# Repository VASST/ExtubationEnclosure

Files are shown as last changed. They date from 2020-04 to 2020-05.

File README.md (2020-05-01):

# Aerosol Containment Enclosure

This page details the design, materials, and construction of an aerosol containment enclosure for hospital settings. It has been developed in a partnership between physicians at University Hospital, London Health Sciences Centre (LHSC) and engineers at Robarts Research Institute (RRI), Western University.

## Publication
This work can be read in detail here:
* [A multipurpose portable negative air flow isolation chamber for aerosol generating medical procedures during the COVID-19 pandemic
Cubillos, J. et al.](https://bjanaesthesia.org/article/S0007-0912(20)30274-9/fulltext)

## Contacts
- Adam Rankin (arankin -at- robarts.ca), RRI, hardware
- John Moore (jmoore -at- robarts.ca), RRI, hardware
- Daniel Bainbridge, LHSC, anesthesiologist
- Kevin Armstrong, LHSC, anesthesiologist
- Javier Cubillos, LHSC, anesthesiologist

## References
- A 3 sided + top design with rigid plastic walls. Excellent spatter containment but no management of dispersal into the surrounding airspace; limited range of motion for physicians; excellent access for tubing/tools/hands:
  - [Barrier Enclosure during Endotracheal Intubation](https://www.nejm.org/doi/full/10.1056/NEJMc2007589)

# Designs
* [Fully 3D Printed Cage](./Designs/Ribcage.md)
* [PVC Pipe Cage](./Designs/HWCage.md)

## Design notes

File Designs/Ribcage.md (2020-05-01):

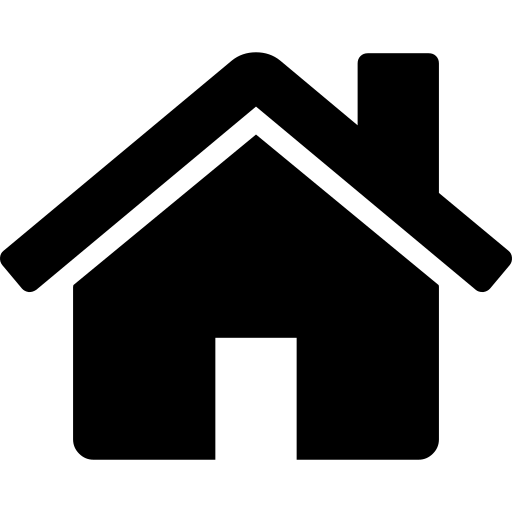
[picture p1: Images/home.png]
[ - Main Page](../README.md)

# Fully 3D Printed Cage
This design is intended to be built using 3D printed, modular parts. Two example designs are presented here, but the idea is that any combination can be used as needed.

## Materials
- 3D printed parts:
  - ABS or PETG recommended as a printing material for cleaning purposes
  - PLA is not recommended due to its lower glass transition and melting points
- Hardware:
  - Use any of: M5x15, 10-24x5/8" or 10-32x5/8" with corresponding nylon lock-nut

## CAD
- [VentilatorFrame-01.4.stp](../Models/VentilatorFrame-01.4.stp)

## Printing
- Parts are designed to be printed on hobby grade 3D printers, use settings as recommended by your printer and filament guidelines

### Parts
- [VentilatorFrame_BaseLong](../Models/VentilatorFrame_BaseLong.stl)
- [VentilatorFrame_BaseShort](../Models/VentilatorFrame_BaseShort.stl)
- [VentilatorFrame_VerticalPost](../Models/VentilatorFrame_VerticalPost.stl)
- [VentilatorFrame_VerticalExtension](../Models/VentilatorFrame_VerticalExtension.stl)
- [VentilatorFrame_HalfArch](../Models/VentilatorFrame_HalfArch.stl)
- [VentilatorFrame_WholeArch](../Models/VentilatorFrame_WholeArch.stl)
- [VentilatorFrame_ArchSpacer](../Models/VentilatorFrame_ArchSpacer.stl)
- [VentilatorFrame_IOPort](../Models/VentilatorFrame_IOPort.stl)

## Sample Arrangements
Presented here are some sample arrangements that may be useful for your needs:

### Example 1
This design features an IO port and easy access to the face at the expense of patient comfort

#### Preview

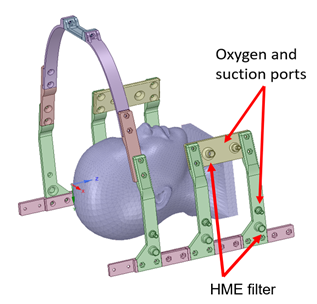
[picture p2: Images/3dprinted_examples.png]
First design preview


#### Quantities
- 6@ VentilatorFrame_VerticalPost
- 2@ VentilatorFrame_VerticalExtension (optional, repeat as many as necessary)
- 2@ VentilatorFrame_IOPort
- 2@ VentilatorFrame_HalfArch
- 1@ VentilatorFrame_ArchSpacer (optional, repeat as many as necessary)
- 2@ VentilatorFrame_BaseShort
- 2@ VentilatorFrame_BaseLong

### Example 2
This configuration provides more room over the patients face, but has limited access from the sides.

#### Preview

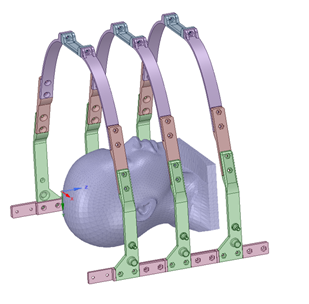
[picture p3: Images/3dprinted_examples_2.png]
Second design preview


#### Quantities
- 6@ VentilatorFrame_VerticalPost
- 6@ VentilatorFrame_VerticalExtension (optional, repeat as many as necessary)
- 6@ VentilatorFrame_HalfArch
- 3@ VentilatorFrame_ArchSpacer (optional, repeat as many as necessary)
- 2@ VentilatorFrame_BaseShort
- 2@ VentilatorFrame_BaseLong

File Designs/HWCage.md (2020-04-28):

[ - Main Page](../README.md)

# PVC Pipe Cage
This design is intended to be built using common plumbing parts that would most likely be available at your local hardware store. A number of 3D printed pieces are included as optional enhancements, but are not necessary for the basic structure.

## Video
A video of the cage in action can be seen at [https://youtu.be/DAdx9pdc0is](https://youtu.be/DAdx9pdc0is)

## North American
Design based on 3/4" ID PVC plumbing pipe

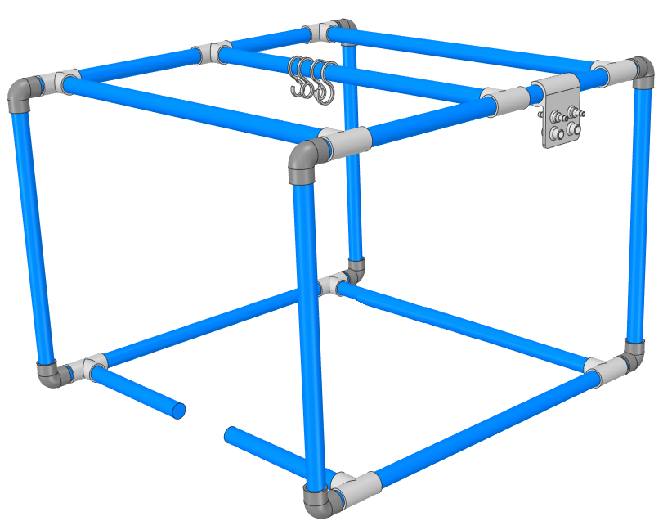
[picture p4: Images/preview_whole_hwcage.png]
Whole design preview


### Materials
- 3/4" pipe sections (example: [https://www.mcmaster.com/48925k12](https://www.mcmaster.com/48925k12]))
  - corner assemblies
    - 8@ 2"
  - side joins
    - 4@ 23.5"
  - side verticals
    - 4@ 18.5"s
  - side horizontals
    - 2@ 21"
    - 4@ 10.5"
  - Optional: 2@ length determined by bed/patient/mounting system (see assembly instructions for detail)
- 3/4" pipe fittings
  - 8@ 90deg female-female (example: [https://www.mcmaster.com/4880k22](https://www.mcmaster.com/4880k22))
  - 10@ Tee: female-female-female (example: [https://www.mcmaster.com/4880k42](https://www.mcmaster.com/4880k42))

### Assembly

First left side, then right side, then join them together.

#### Right Side: Preview

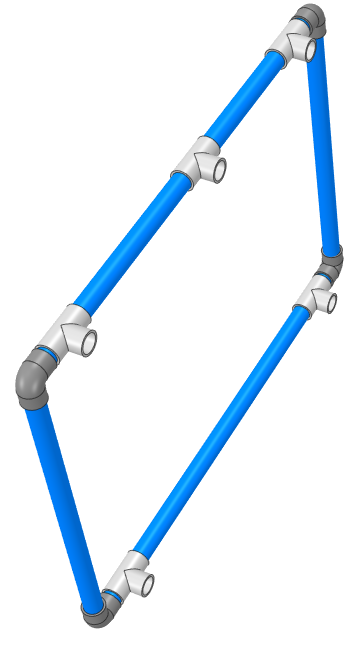
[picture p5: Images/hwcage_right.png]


##### Materials
Per side:

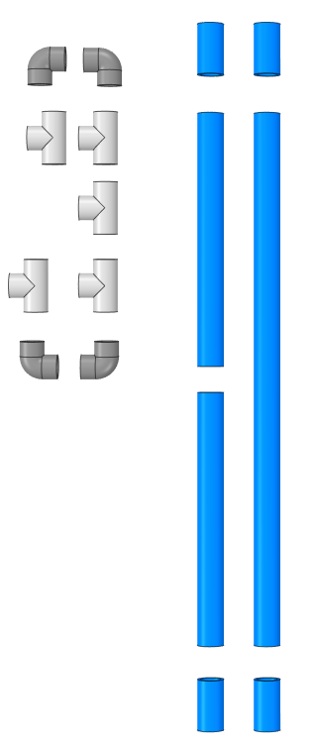
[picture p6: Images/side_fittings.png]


##### Steps

1. Build corner assemblies by gluing a 2" section to a corner and a tee fitting. Ensure that the corner bend direction is perpendicular to the tee perpendicular fitting (see image). Create 4 of these (2 per side).
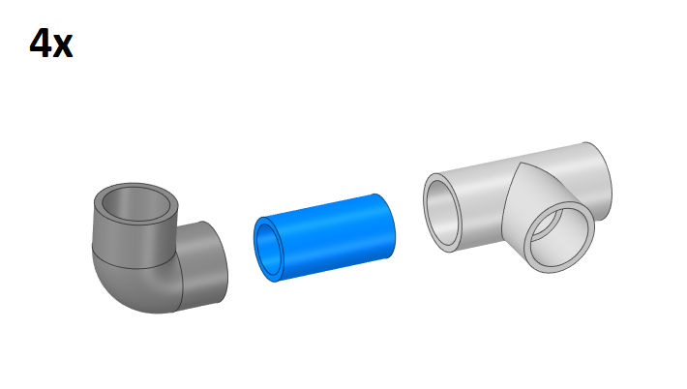
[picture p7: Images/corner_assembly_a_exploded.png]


1. Similarly to the first step, create 4 more corner assemblies, but with the tee bracket turned 180 degrees from your first 4.
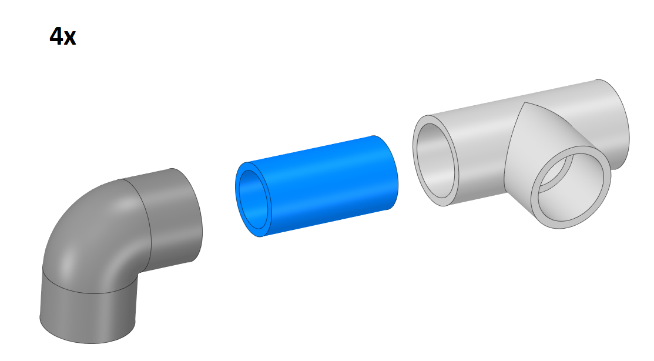
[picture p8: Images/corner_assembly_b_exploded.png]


1. Glue the corner pieces into two horizontal assemblies, the top one having a tee fitting in between two 10" sections of pipe, and the bottom one consisting solely of a 21" piece of pipe.
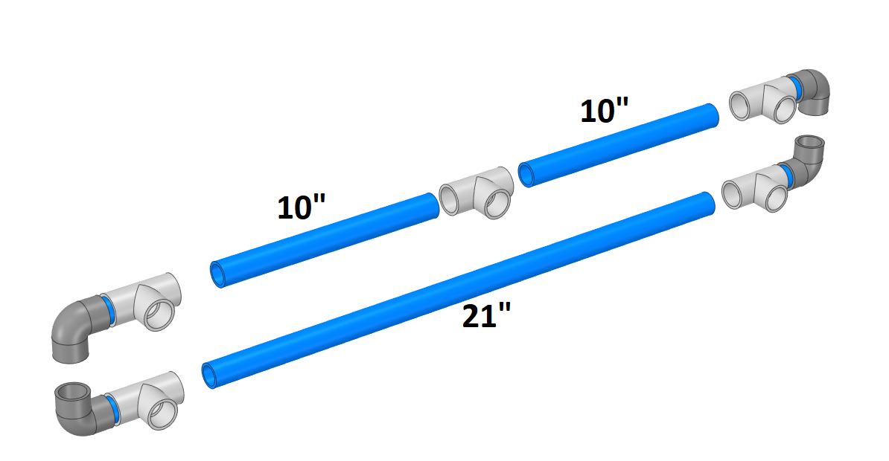
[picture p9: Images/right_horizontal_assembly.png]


1. Glue the two horizontal assemblies together using two 18.5" pieces of pipe.
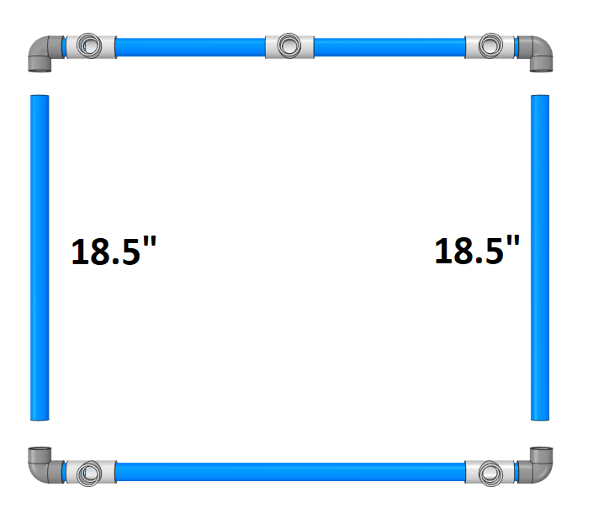
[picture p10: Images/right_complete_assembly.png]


#### Left Side

Repeat but assembly corners such that they form a mirror of the right side.

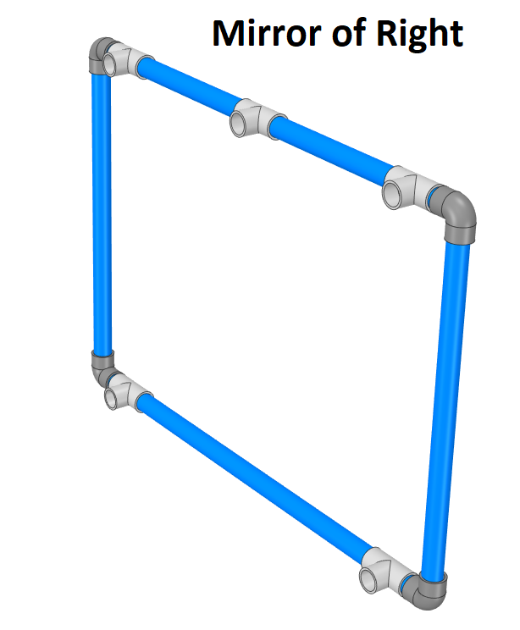
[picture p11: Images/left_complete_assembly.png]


#### Combine Sides
**Do not glue!** Use 23.5" pipes to join two sides. Pipes are left unglued to allow for diassembly and compact storage.

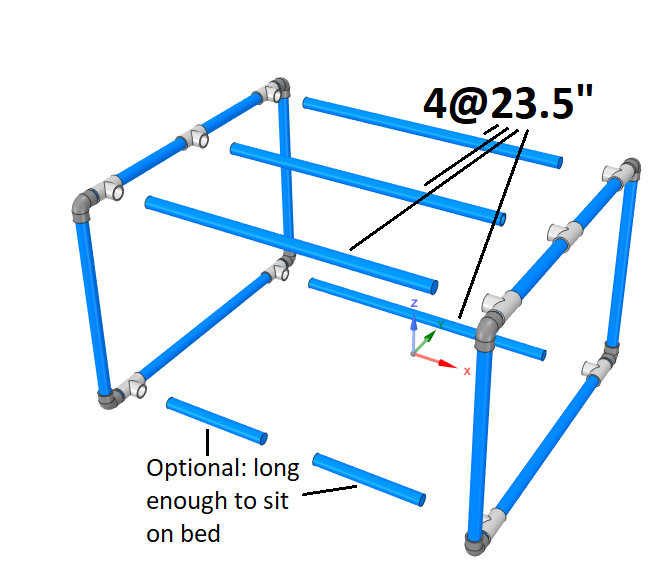
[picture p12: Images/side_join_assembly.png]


### Optional Pieces
1. [gas_port_IO_corner_US](../Models/gas_port_IO_corner_US.stl)
1. [gas_port_IO_snapOn_US](../Models/gas_port_IO_snapOn_US.stl)
1. S-hooks
    1. [S_hook_0.6in_US](../Models/S_hook_0.6in_US.stl)
    1. [S_hook_0.787in_US](../Models/S_hook_0.787in_US.stl)
    1. [S_hook_0.787in_closed_US](../Models/S_hook_0.787in_closed_US.stl)
    1. [S_hook_1.181in_US](../Models/S_hook_1.181in_US.stl)

## European/Metric
For those who work with the metric system, replace all 3/4" pipe and fittings with DN 20mm rigid PVC pipe or nearest equivalent that is easily sourced near you.

### Optional Pieces
S-hooks can be printed at scale: 1.0499 (20/19.05) to fit nicely on DN 20mm.

1. [gas_port_IO_corner_EU](../Models/gas_port_IO_corner_EU.stl)
1. [gas_port_IO_snapOn_EU](../Models/gas_port_IO_snapOn_EU.stl)

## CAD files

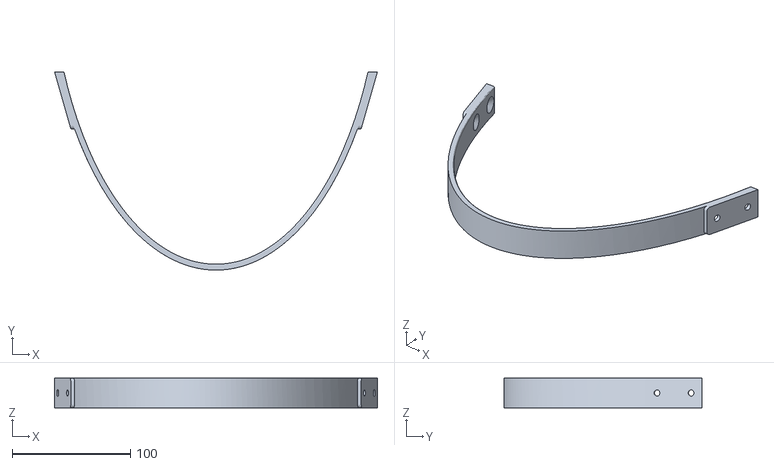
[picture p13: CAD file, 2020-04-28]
Models/VentilatorFrame_WholeArch.stl
272.9 x 167.5 x 25.0

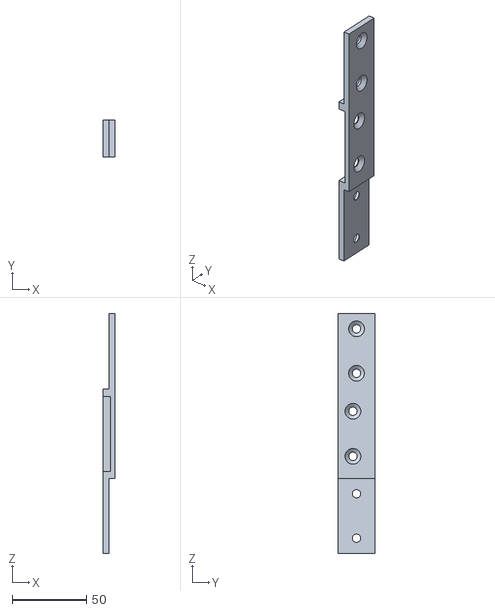
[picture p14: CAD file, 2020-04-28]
Models/VentilatorFrame_BaseShort.stl
8.00 x 25.0 x 161.9

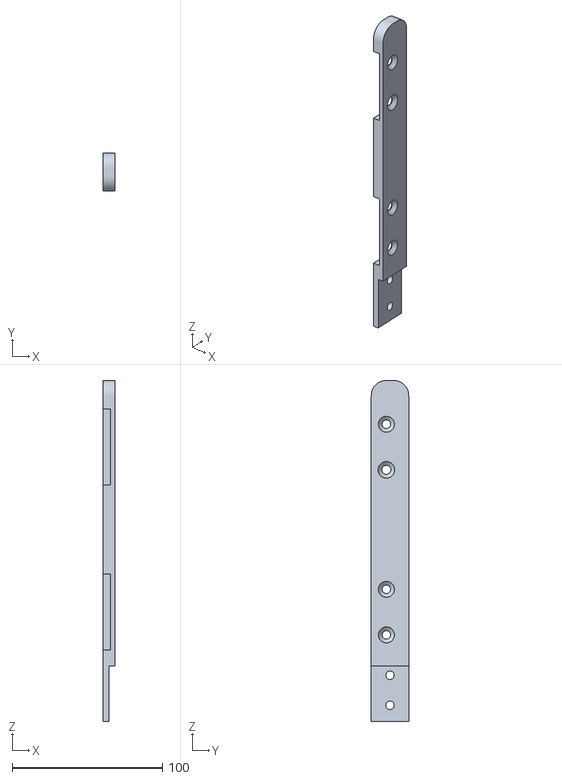
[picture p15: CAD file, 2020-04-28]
Models/VentilatorFrame_BaseLong.stl
8.00 x 25.0 x 227.2

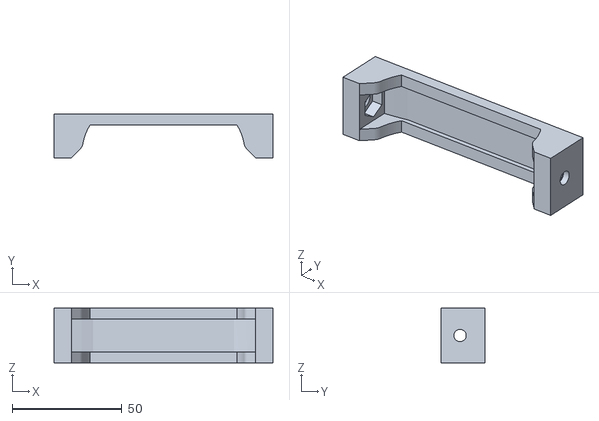
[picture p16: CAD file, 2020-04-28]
Models/VentilatorFrame_ArchSpacer.stl
100.0 x 19.9 x 25.0

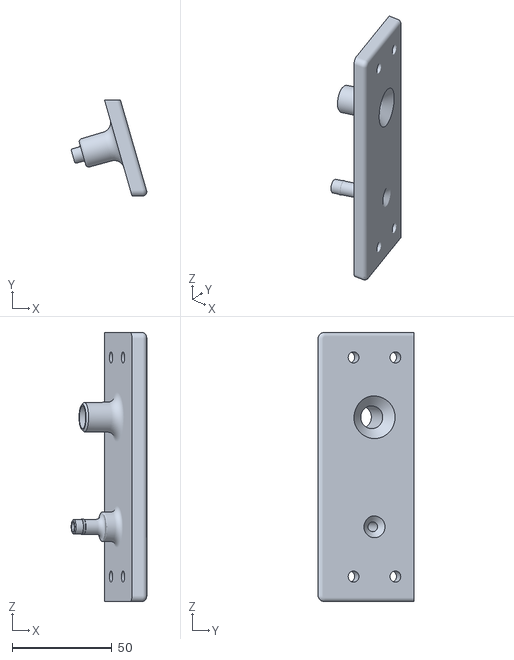
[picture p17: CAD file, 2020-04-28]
Models/VentilatorFrame_IOPort.stl
37.9 x 48.1 x 135.0

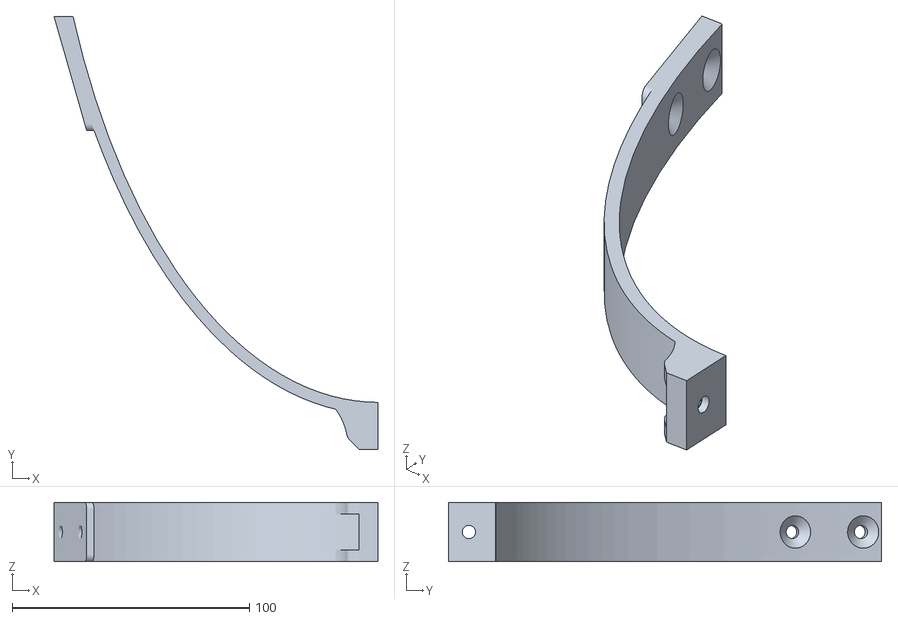
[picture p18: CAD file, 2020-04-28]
Models/VentilatorFrame_HalfArch.stl
136.5 x 182.4 x 25.0

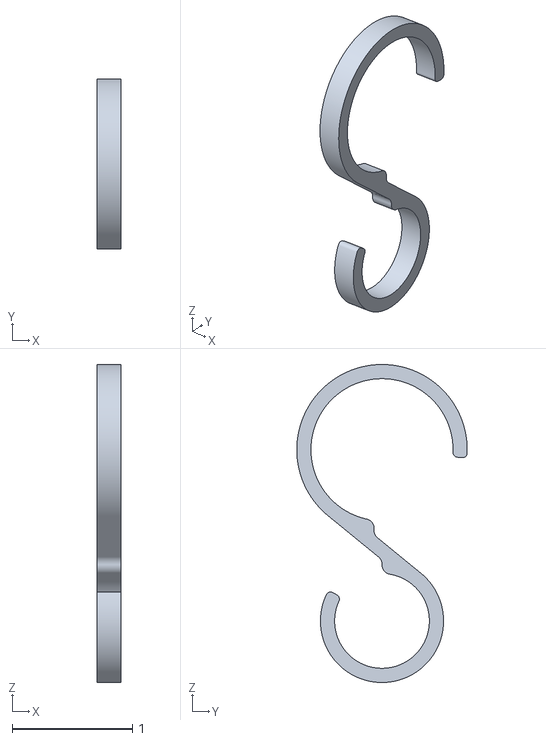
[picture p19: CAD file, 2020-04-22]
Models/S_hook_0.787in_US.stl
0.197 x 1.42 x 2.64

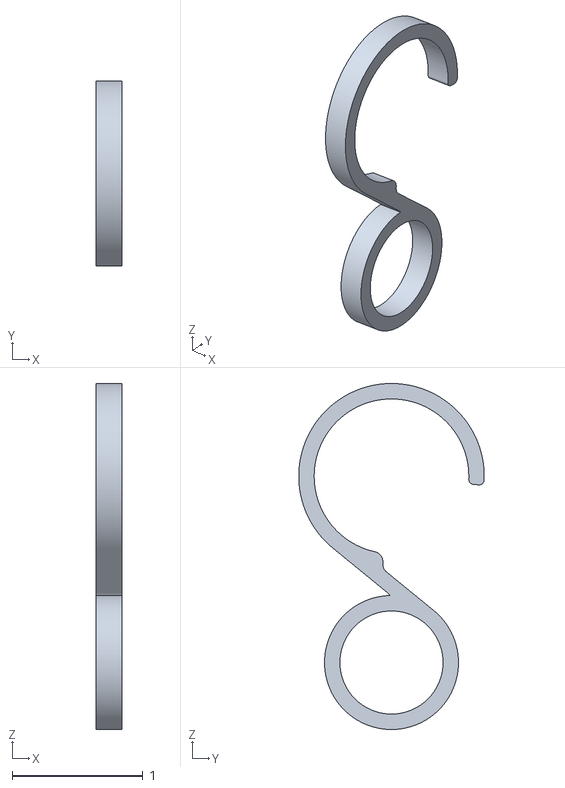
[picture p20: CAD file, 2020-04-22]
Models/S_hook_0.787in_closed_US.stl
0.197 x 1.42 x 2.64

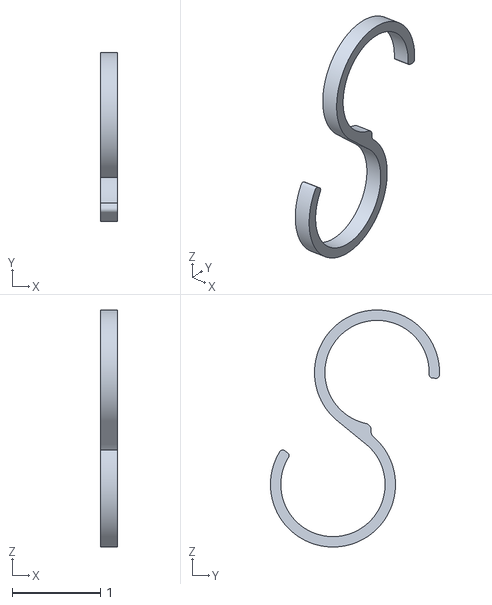
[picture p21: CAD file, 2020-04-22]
Models/S_hook_1.181in_US.stl
0.197 x 1.92 x 2.69

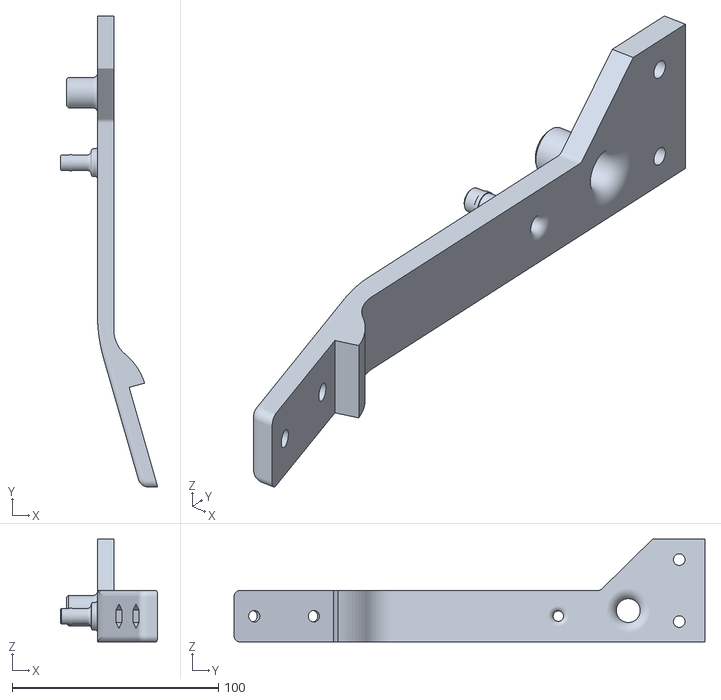
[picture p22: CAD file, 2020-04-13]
Models/VentilatorFrame_VerticalPost.stl
47.2 x 228.1 x 49.9

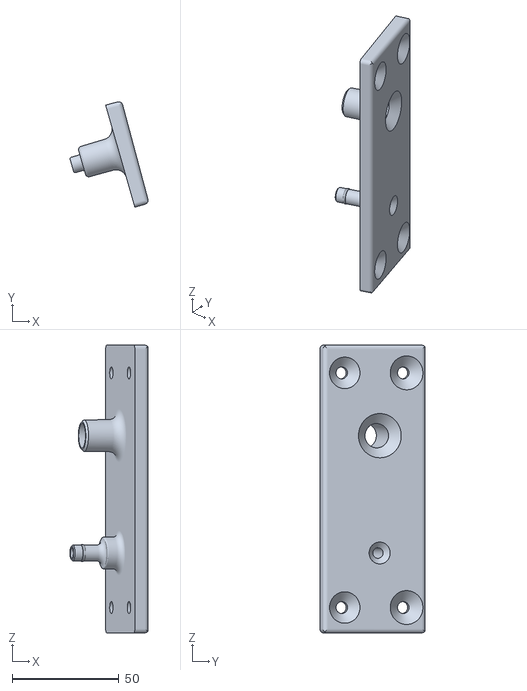
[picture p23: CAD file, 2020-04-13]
Models/Air-Io-singleSided.stl
36.6 x 49.4 x 135.0

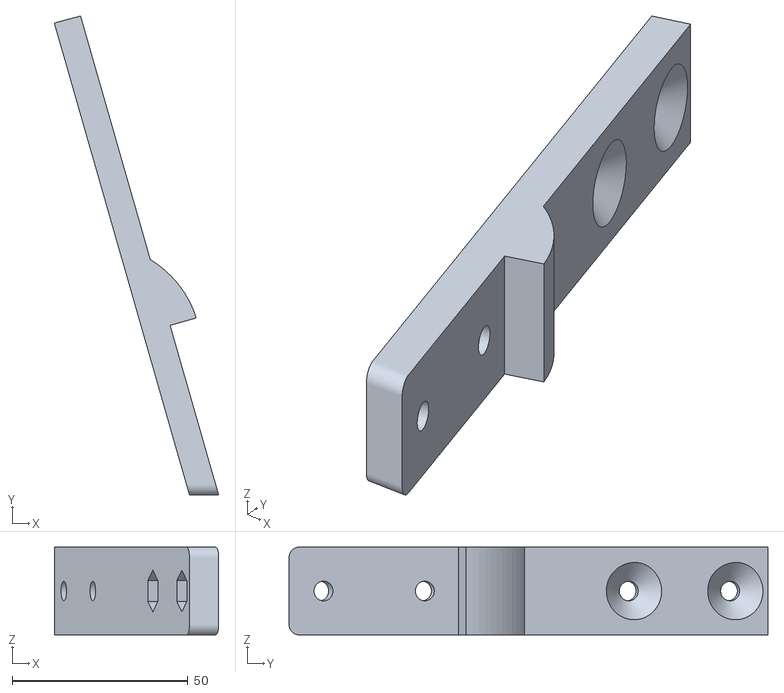
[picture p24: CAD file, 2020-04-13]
Models/VentilatorFrame_VerticalExtension.stl
46.8 x 136.3 x 25.0

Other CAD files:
Models/S_hook_0.6in_US.stl

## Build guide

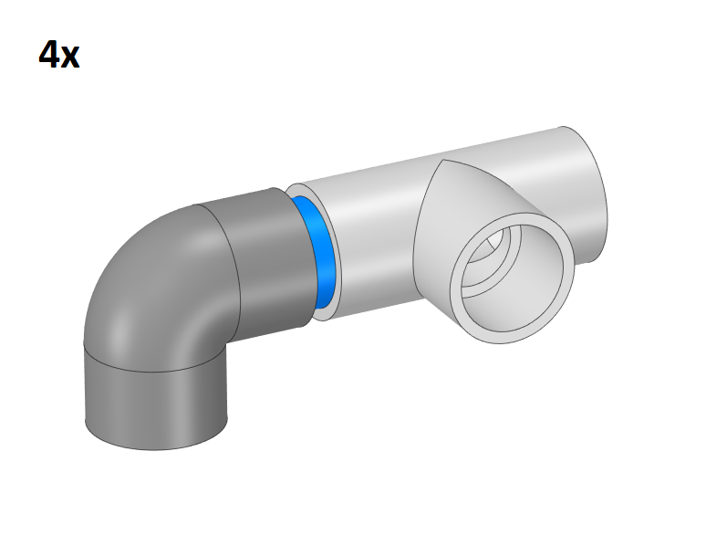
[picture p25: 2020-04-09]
Images/corner_assembly_b.png

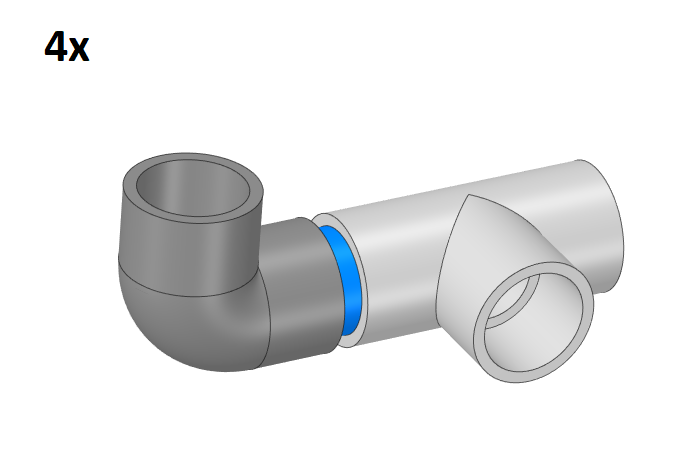
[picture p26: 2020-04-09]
Images/corner_assembly_a.png

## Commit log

2020-04-09 [WIP] first draft, reboot interrupted
2020-04-13 add models
    add license
    [Air-Io-singleSided.stl, Arch.stl, Base.stl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]
